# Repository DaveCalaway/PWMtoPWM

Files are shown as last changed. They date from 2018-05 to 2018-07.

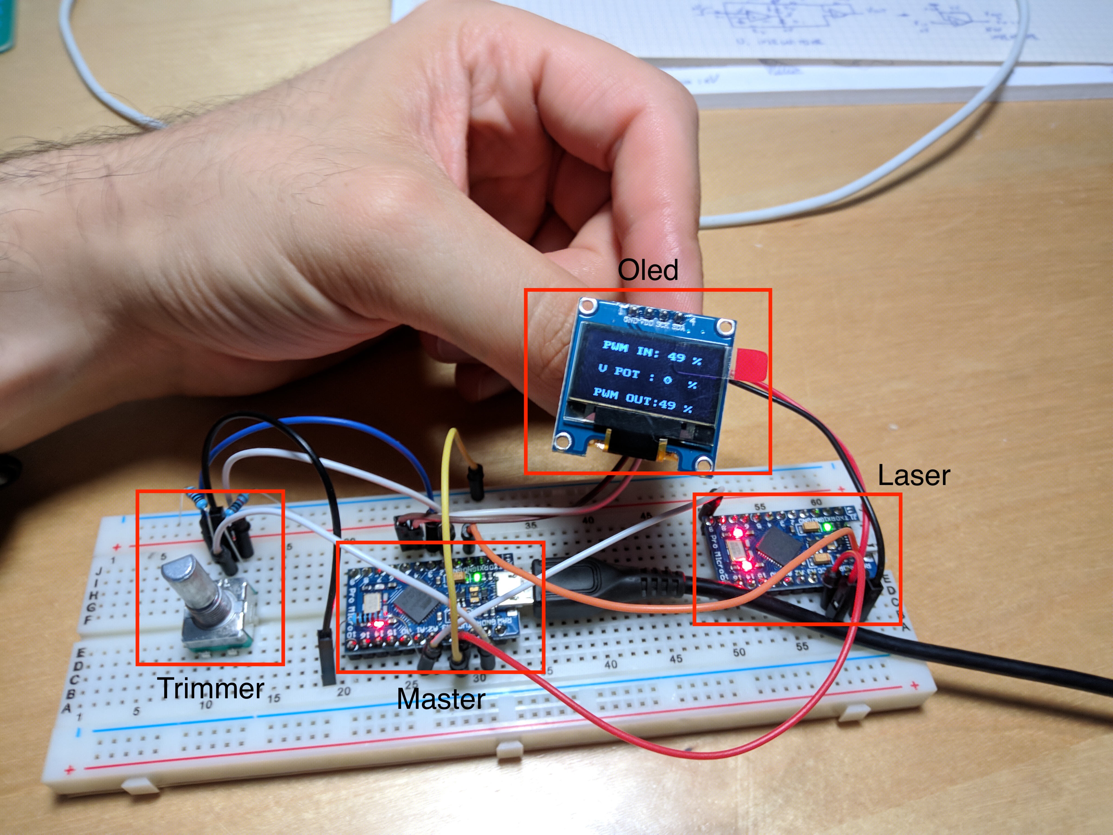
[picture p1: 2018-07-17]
SetUp copy.jpg

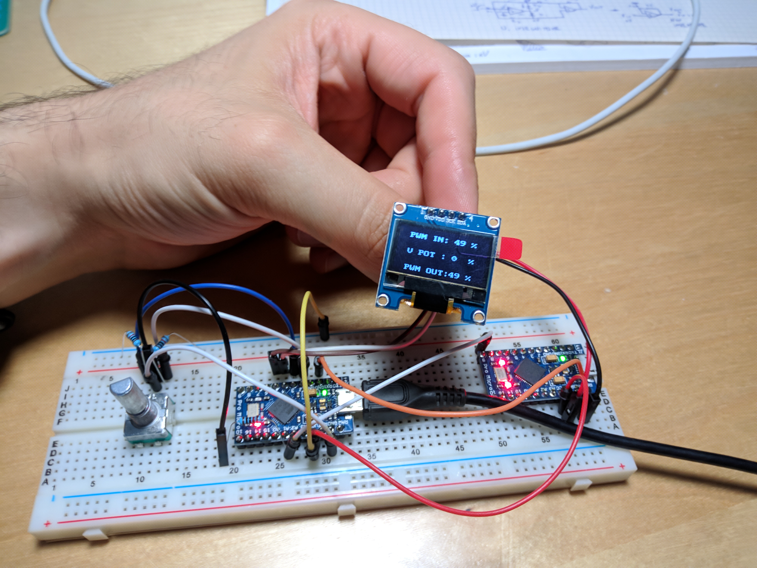
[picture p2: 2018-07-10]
SetUp.jpg

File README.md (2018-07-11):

# PWMtoPWM

In that repo we have 2 project:
- **pwmTOpwm**: example with potentiometer
  - Status: Stable.
  - No Kicad board
- **pwmTOpwm_dual**: example with encoder
  - Status: pre Release candidate
  - Kicad board

<p align="center">
  
</p>
  
  Dave Calaway.

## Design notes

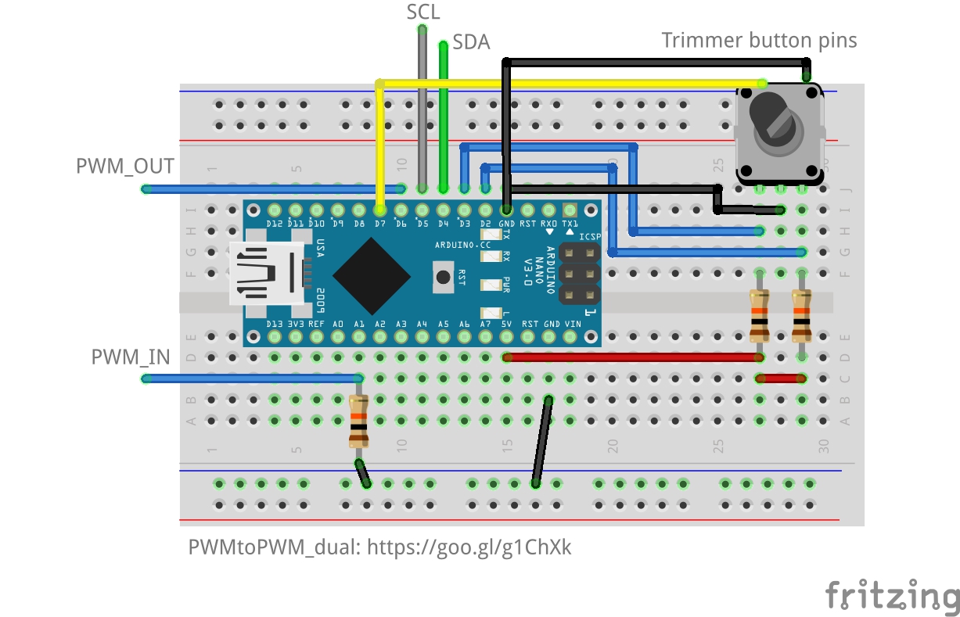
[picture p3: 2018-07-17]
pwmTOpwm_dual/pwmTOpwm_bb.jpg

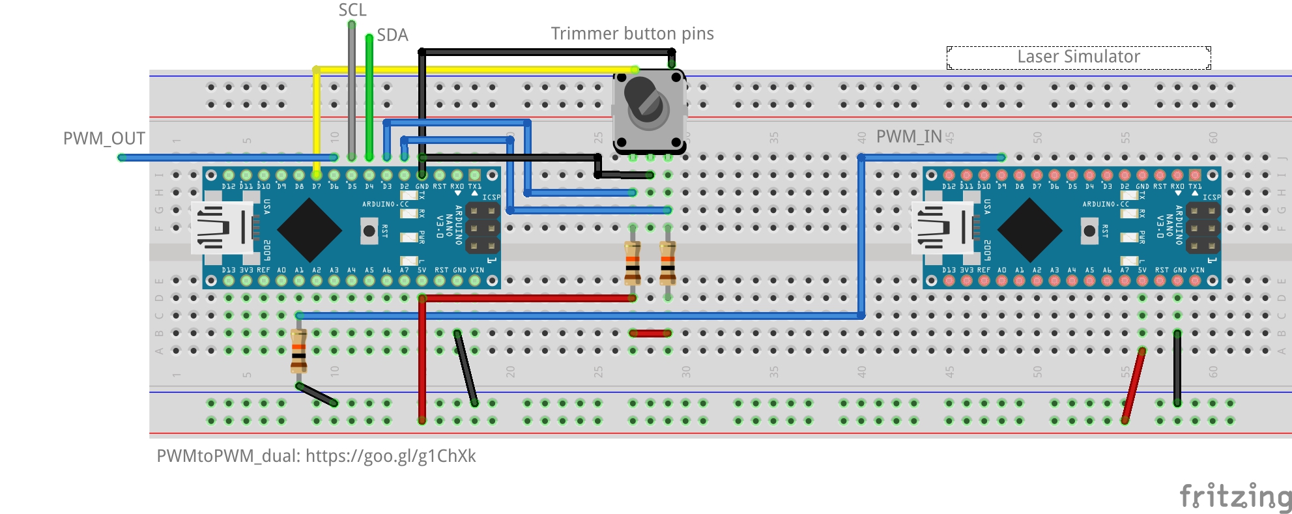
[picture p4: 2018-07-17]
pwmTOpwm_dual/pwmTOpwm+laser_bb.jpg

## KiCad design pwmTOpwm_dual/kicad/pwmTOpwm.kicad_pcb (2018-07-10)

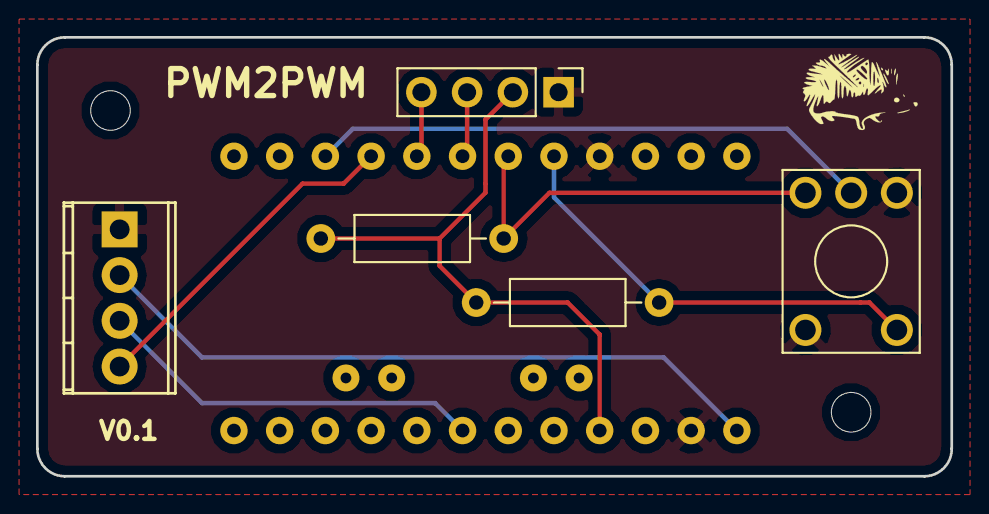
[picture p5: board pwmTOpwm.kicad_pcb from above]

Board: 2 copper layers, 50.8 x 24.4 mm, 6 parts (0 on the bottom side), 10 nets.

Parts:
J1: Conn_01x04; Pin_Header_Straight_1x04_Pitch2.54mm
J2: Screw_Terminal_01x04; TerminalBlock_Phoenix_MPT-2.54mm_4pol
R1, R2: 10k; R_Axial_DIN0207_L6.3mm_D2.5mm_P10.16mm_Horizontal
SW1: Rotary_Encoder_Switch; KSA_Tactile_SPST
uP1: ARDUPROMINI-6; ArduProMini-6

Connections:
/A: R2.2, SW1.1, uP1.11
/B: R1.2, SW1.3, uP1.12
/SCL: J1.3, uP1.13
/SDA: J1.4, uP1.14
/VCC: J1.2, R1.1, R2.1, uP1.22
/Vin: J2.2, uP1.19
/button: SW1.4, uP1.16
/pwm_in: J2.3, uP1.25
/pwm_out: J2.4, uP1.15
GND: J1.1, J2.1, SW1.2, SW1.5, uP1.10, uP1.20

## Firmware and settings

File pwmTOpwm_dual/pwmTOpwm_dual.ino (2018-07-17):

/*
  PWM to PWM with Encoder

  Library:
  - Encoder: https://goo.gl/g9Udvb
  - U8x8lib : https://goo.gl/vvKczz

  This example change the a pwm_in pulse in to other pwm_in pulse.
  Oled display integration: SCL = 5 -- SDA = 4

  Theory of PWM signal in Arduino:
  Arduino PWM has period of 490Hz -> 0.002040s
  This means that the PWM singal gose to 0 = 0Hz = 0s to 255 = 490Hz = 0.002040s
  pulseIn return us, so 0.002040s become 2040 us.

  DaveCalaway
*/

#include <U8x8lib.h>
#include <Encoder.h>

#define button_pin 7
#define pwm_in_pin A1
#define pwm_out_pin 6
#define ref 500 // refresh the screen ms

long previousMillis = 0;
int pwm_in = 0;
int pwm_out = 0;
bool stato = 0;
float EMA_a_pulse = 0.4;
unsigned long EMA_S_pulse = 0;
int oldPosition  = -999;
int oldpwm_in = 0;
int newPosition = 0;

// Change these two numbers to the pins connected to your encoder.
//   Best Performance: both pins have interrupt capability
//   Good Performance: only the first pin has interrupt capability
//   Low Performance:  neither pin has interrupt capability
Encoder myEnc(3, 2); // on the Pro Mini / UNO ecc....

// OLEDs without Reset of the Display
U8X8_SSD1306_128X64_NONAME_SW_I2C u8x8(/* clock=*/ 5, /* data=*/ 4, /* reset=*/ U8X8_PIN_NONE);

void setup() {
  //Serial.begin(115200);
  pinMode(button_pin, INPUT_PULLUP);
  u8x8.begin();
  u8x8.setFont(u8x8_font_pxplustandynewtv_u);
}

void loop() {

  // Read the PWM_in
  unsigned long pulse = pulseIn(pwm_in_pin, HIGH, 125000); // pulse 0 - 2040
  //Serial.println(pulse);
  // media pulse
  EMA_S_pulse = (EMA_a_pulse * pulse) + ((1 - EMA_a_pulse) * EMA_S_pulse); //run the EMA
  pwm_in = map(EMA_S_pulse, 0, 2040, 0, 100);

  // LASER ON
  if ( pulse > 10 ) {
    stato = 1;
    // Reset
    if (digitalRead(button_pin) == 0) {
      delay(15);
      myEnc.write(0);
    }
    // Read Encoder
    else {
      newPosition = myEnc.read();
      // 0 < pwm_in + newPosition < 99
      if ( ((pwm_in + newPosition) <= 98) && ((pwm_in + newPosition) > 2)) {
        pwm_out = map(pwm_in + newPosition, 0, 100, 0, 255);
        analogWrite(pwm_out_pin, pwm_out);
      }
      else {
        if ( pwm_in + newPosition > 98 ) {
          newPosition = 98 - pwm_in; // calculate the max/min value can be displayed
          myEnc.write(newPosition);
        }
        else { // pwm_in + (-)newPosition < 0
          newPosition = 98 - pwm_in; // calculate the max/min value can be displayed
          newPosition = (-1) * newPosition;
          myEnc.write(newPosition);
        }
      }
    }
  }
  // LASER OFF
  else {
    stato = 0;
    analogWrite(pwm_out_pin, 0);
  }

  // ------------- Display  -------------
  if (millis() - previousMillis >= ref && pulse != 0 ) {
    previousMillis = millis();

    u8x8.setCursor(2, 1);
    u8x8.print("PWM IN:");
    if ( stato == 0)
      pwm_in = 0;
    if (pwm_in < 10) {
      u8x8.setCursor(11, 1);
      u8x8.print(".");
    }
    else {
      u8x8.setCursor(10, 1);
      u8x8.print(pwm_in);
      u8x8.setCursor(13, 1);
      u8x8.print("%");
    }

    u8x8.setCursor(2, 12);
    u8x8.print("V POT :");
    if (newPosition < 10 && newPosition > -10) {
      u8x8.setCursor(11, 12);
      u8x8.print("  ");
    }
    u8x8.setCursor(10, 12);
    u8x8.print(newPosition);
    u8x8.setCursor(13, 12);
    u8x8.print("%");

    u8x8.setCursor(2, 23);
    u8x8.print("PWM OUT:");
    int out = pwm_in + newPosition;
    if ( stato == 0)
      out = 0;
    if (out < 10) {
      u8x8.setCursor(11, 23);
      u8x8.print(" ");
    }
    u8x8.setCursor(10, 23);
    u8x8.print(out);
    u8x8.setCursor(13, 23);
    u8x8.print("%");
  }
}

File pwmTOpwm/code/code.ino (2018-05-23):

/*
  PWM to PWM

  This example change the a pwm_in pulse in to other pwm_out pulse.
  Oled display integration: SCL = 3 -- SDA = 2

  Theory of PWM signal in Arduino:
  Arduino PWM has period of 490Hz -> 0.002040s
  This means that the PWM singal gose to 0 = 0Hz = 0s to 255 = 490Hz = 0.002040s
  pulseIn return us, so 0.002040s become 2040 us.

*/

#include <U8x8lib.h>
#define pot_pin A0
#define pwm_in_pin A1
#define pwm_out_pin 6
#define ref 500 // refresh the screen ms

// ------ Correlation
#define Vpot_max 720 // that value is correlated to the EMA_a_Vpot
// if you want to change the EMA_a_Vpot, you must change the Vpot_max.
// Yes, i want to change EMA_a_Vpot:
// 1. change 0 < EMA_a_Vpot < 1
// 2. uncomment #define calibration
//#define calibration
// 3. put the potentiometer at the maximum value
// 4. change Vpot_max to the maximum value you have read from the serial + 5
// 5. comment #define calibration

long previousMillis = 0;
int pwm_out = 0;

float EMA_a_Vpot = 0.6;      //initialization of EMA
int EMA_S_Vpot = 0;

float EMA_a_pulse = 0.4;
int EMA_S_pulse = 0;

U8X8_SSD1306_128X64_NONAME_SW_I2C u8x8(/* clock=*/ SCL, /* data=*/ SDA, /* reset=*/ U8X8_PIN_NONE);   // OLEDs without Reset of the Display

void setup() {
  //Serial.begin(115200);
  u8x8.begin();
  u8x8.setFont(u8x8_font_pxplustandynewtv_u);
  EMA_S_Vpot = analogRead(pot_pin);  //set EMA S for t=1
}

void loop() {

  // Read the PWM_in
  unsigned long pulse = pulseIn(pwm_in_pin, HIGH); // pulse 0 - 2040
  // media pulse
  EMA_S_pulse = (EMA_a_pulse * pulse) + ((1 - EMA_a_pulse) * EMA_S_pulse); //run the EMA
  pwm_out = map(EMA_S_pulse, 0, 2040, 0, 255);

  // Read Vpot
  int Vpot = analogRead(pot_pin);  // Vpot 0 - 1023
  // media Vpot
  EMA_S_Vpot = (EMA_a_Vpot * Vpot) + ((1 - EMA_a_Vpot) * EMA_S_Vpot); //run the EMA
#ifdef calibration
  Serial.println(EMA_S_Vpot);
#endif
  EMA_S_Vpot = map(EMA_S_Vpot, 0, Vpot_max, 0, 255);

  if ( pulse > 2 ) { // Is the Laser ON ?
    if (EMA_S_Vpot > 5) {  // Vpot > Vpot_min_sensibility -> put PWM_out + Vpot
      pwm_out = pwm_out + ( map( EMA_S_Vpot, 0, 255, 0, 255 - pwm_out ) );
      analogWrite(pwm_out_pin, pwm_out);
    }

    else {// Vpot < Vpot_min_sensibility -> copy the PWM_in to PWM_out
      analogWrite(pwm_out_pin, pwm_out);
    }
  }
  else { // The laser is OFF.
    analogWrite(pwm_out_pin, 0);
    pwm_out = 0;
  }

  // ------------- Display
  if (millis() - previousMillis >= ref) {
    byte val = 0;
    previousMillis = millis();

    u8x8.setCursor(2, 1);
    u8x8.print("PWM IN:");
    val = map(pulse, 0, 2040, 0, 100);

    if (val < 10) {
      u8x8.setCursor(11, 1);
      u8x8.print(".");
    }
    else {
      u8x8.setCursor(10, 1);
      u8x8.print(val);
      u8x8.setCursor(13, 1);
      u8x8.print("%");
    }

    u8x8.setCursor(2, 12);
    u8x8.print("V POT :");
    val = map(EMA_S_Vpot, 0, 255, 0, 100);
    if (val < 10) {
      u8x8.setCursor(11, 12);
      u8x8.print(" ");
    }
    u8x8.setCursor(10, 12);
    u8x8.print(val);
    u8x8.setCursor(13, 12);
    u8x8.print("%");

    u8x8.setCursor(2, 23);
    u8x8.print("PWM OUT:");
    val = map(pwm_out, 0, 255, 0, 100);
    if (val < 10) {
      u8x8.setCursor(11, 23);
      u8x8.print(" ");
    }
    u8x8.setCursor(10, 23);
    u8x8.print(val);
    u8x8.setCursor(13, 23);
    u8x8.print("%");
  }
}

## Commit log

2018-05-18 init
    bug in the little Vpot measurements
    [code.ino]
2018-05-19 Beta + schematic
    [pwmTOpwm.fzz]
2018-05-23 single number display fixed
    [code.ino]
2018-07-10 potentiometer version
    [pwmTOpwm-B.Cu.gbr, pwmTOpwm-B.Mask.gbr, pwmTOpwm-B.SilkS.gbr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]
2018-07-10 Auto stash before rebase of "origin/master"
    [pwmTOpwm.fzz]
2018-07-17 Laser sim added
    [pwmTOpwm+laser.fzz, pwmTOpwm.fzz]
